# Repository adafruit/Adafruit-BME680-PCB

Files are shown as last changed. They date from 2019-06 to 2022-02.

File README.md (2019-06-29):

## Adafruit BME680 PCB

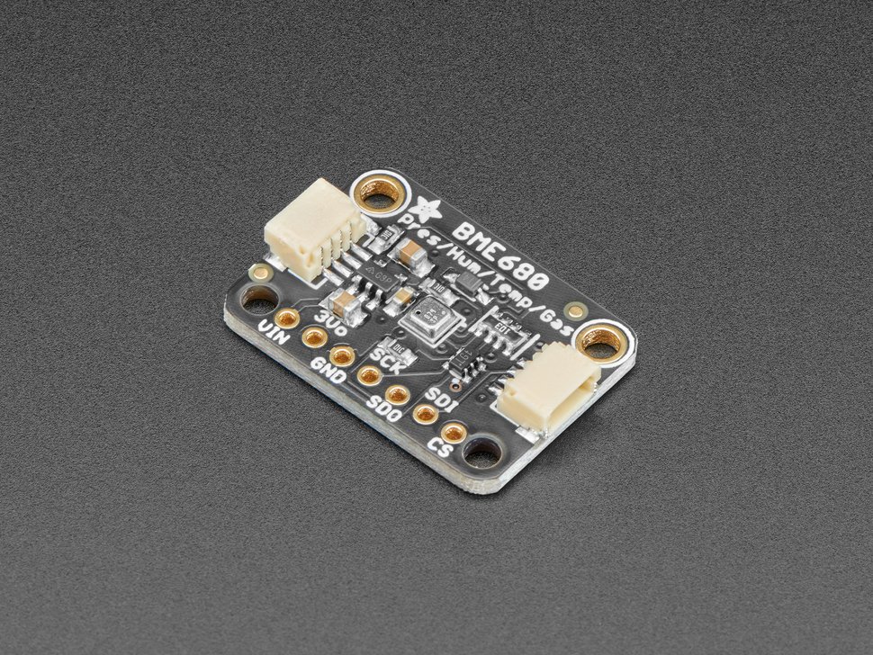
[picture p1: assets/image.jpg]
<a href="http://www.adafruit.com/products/3660"><br/>
Click here to purchase one from the Adafruit shop</a>

PCB files for the Adafruit BME680 Breakout. Format is EagleCAD schematic and board layout

For more details, check out the product page at
* https://www.adafruit.com/product/3660

### Description

The long awaited BME680 from Bosch gives you all the environmental sensing you want in one small package. This little sensor contains temperature, humidity, barometric pressure, and VOC gas sensing capabilities. All over SPI or I2C at a great price!

Like the BME280 & BMP280, this precision sensor from Bosch can measure humidity with ±3% accuracy, barometric pressure with ±1 hPa absolute accuracy, and temperature with ±1.0°C accuracy. Because pressure changes with altitude, and the pressure measurements are so good, you can also use it as an altimeter with  ±1 meter or better accuracy!

The BME680 takes those sensors to the next step in that it contains a small MOX sensor. The heated metal oxide changes resistance based on the volatile organic compounds (VOC) in the air, so it can be used to detect gasses & alcohols such as Ethanol, Alcohol and Carbon Monoxide, and perform air quality measurements. Note it will give you one resistance value, with overall VOC content, but it cannot differentiate gasses or alcohols.

Please note this sensor, like all VOC/gas sensors, has variability and to get precise measurements you will want to calibrate it against known sources! That said, for general environmental sensors, it will give you a good idea of trends and comparisons. We recommend that you run this sensor for 48 hours when you first receive it to "burn it in", and then 30 minutes in the desired mode every time the sensor is in use. This is because the sensitivity levels of the sensor will change during early use, and the resistance will slowly rise over time as the MOX warms up to its baseline reading.

For your convenience we've pick-and-placed the sensor on a PCB with a 3.3V regulator and some level shifting, so it can be easily used with your favorite 3.3V or 5V microcontroller.

### License

Adafruit invests time and resources providing this open source design, please support Adafruit and open-source hardware by purchasing products from [Adafruit](https://www.adafruit.com)!

Designed by Limor Fried/Ladyada for Adafruit Industries.

Creative Commons Attribution/Share-Alike, all text above must be included in any redistribution. See license.txt for additional details.

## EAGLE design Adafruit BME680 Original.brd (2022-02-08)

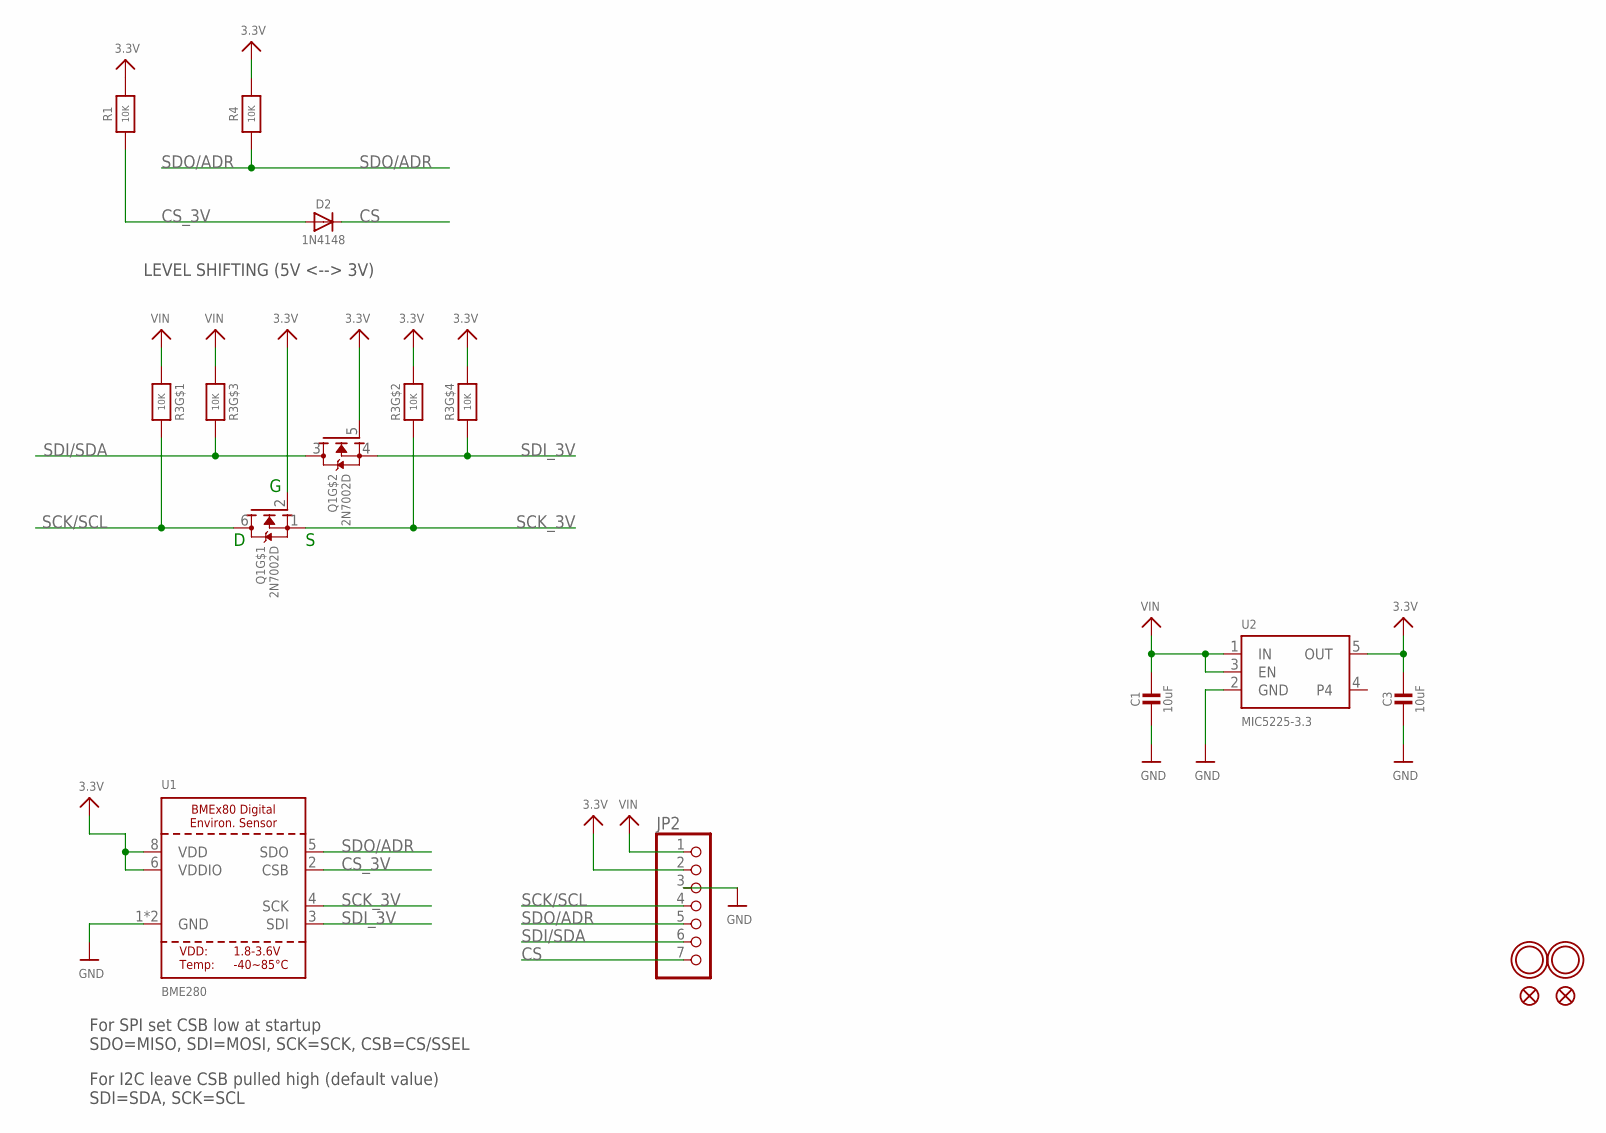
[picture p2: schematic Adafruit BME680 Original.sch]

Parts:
C1, C3: 10uF; 0805-NO
D2: 1N4148; SOD-323
JP2: HEADER-1X770MIL; 1X07_ROUND_70
Q1: 2N7002D; SOT363
R1, R4: 10K; 0603-NO
R3: 10K; RESPACK_4X0603
U1: BME280; BME680
U2: MIC5225-3.3; SOT23-5
U$5, U$15: FIDUCIAL_1MM
U$7, U$8: MOUNTINGHOLE2.0; MOUNTINGHOLE_2.0_PLATED

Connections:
3.3V: C3.1, JP2.2, Q1.2 (G), Q1.5 (G), R1.2, R3.2 (1), R3.4 (1), R4.2, U1.6 (VDDIO), U1.8 (VDD), U2.5 (OUT)
CS: D2.C, JP2.7
CS_3V: D2.A, R1.1, U1.2 (CSB)
GND: C1.2, C3.2, JP2.3, U1.1 (GND), U1.7 (GND), U2.2 (GND)
SCK/SCL: JP2.4, Q1.6 (D), R3.8 (2)
SCK_3V: Q1.1 (S), R3.7 (2), U1.4 (SCK)
SDI/SDA: JP2.6, Q1.3 (D), R3.6 (2)
SDI_3V: Q1.4 (S), R3.5 (2), U1.3 (SDI)
SDO/ADR: JP2.5, R4.1, U1.5 (SDO)
VIN: C1.1, JP2.1, R3.1, R3.3 (1), U2.1 (IN), U2.3 (EN)

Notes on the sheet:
For SPI set CSB low at startup SDO=MISO, SDI=MOSI, SCK=SCK, CSB=CS/SSEL
For I2C leave CSB pulled high (default value) SDI=SDA, SCK=SCL
LEVEL SHIFTING (5V <--> 3V)

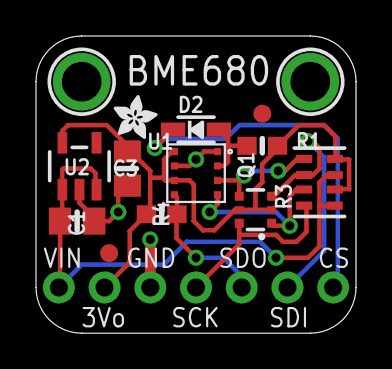
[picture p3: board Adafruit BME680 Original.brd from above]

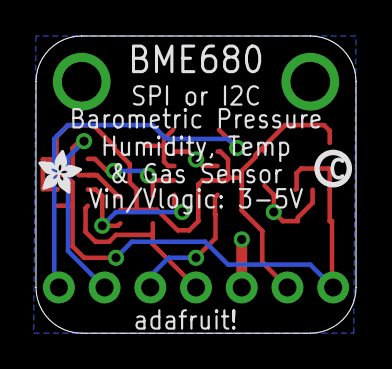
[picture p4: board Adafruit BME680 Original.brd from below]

Board: 2 copper layers, 17.8 x 16.5 mm, 17 parts (2 on the bottom side), 10 nets.

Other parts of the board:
U$2, U$6: ADAFRUIT_2.5MM
U$20: PCBFEAT-REV-040

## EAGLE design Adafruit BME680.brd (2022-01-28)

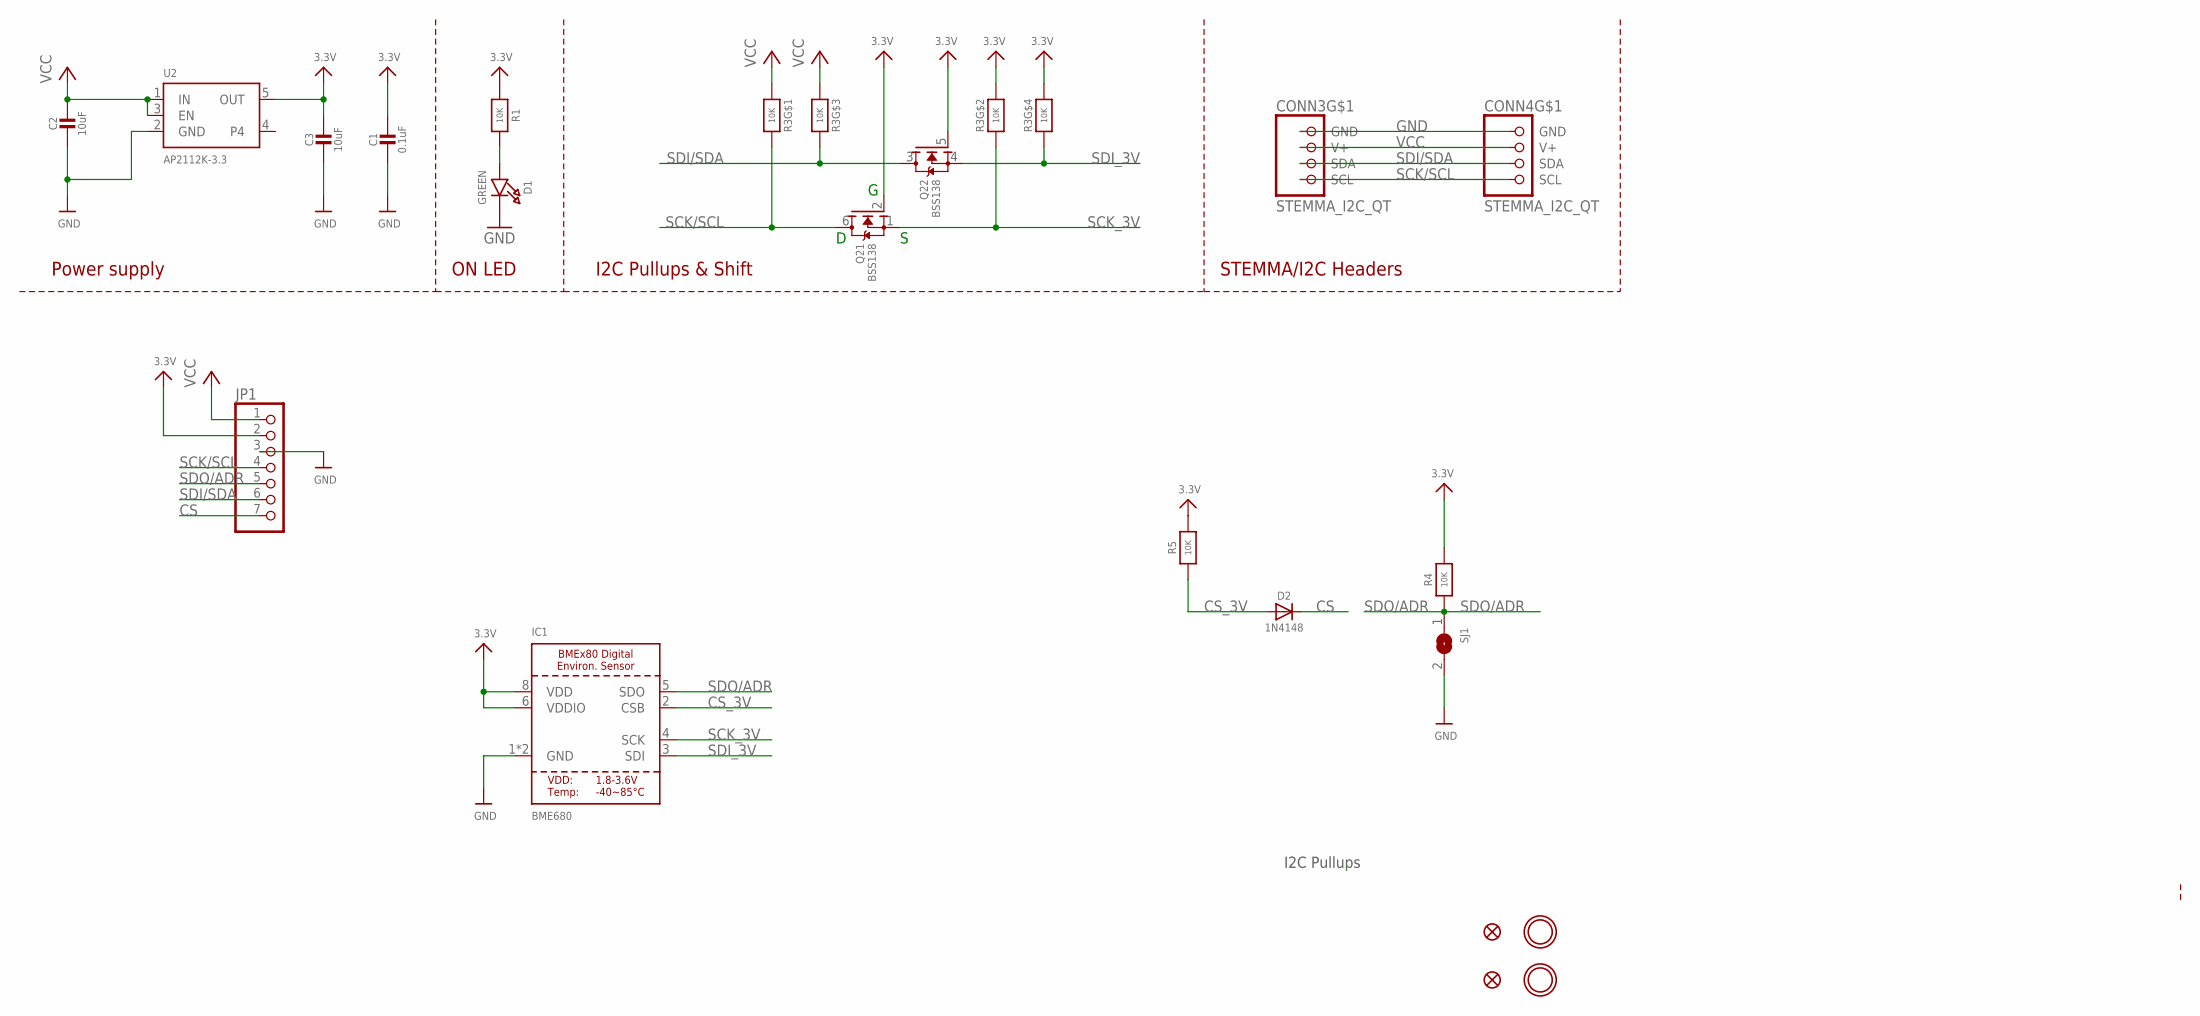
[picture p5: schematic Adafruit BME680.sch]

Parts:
C1: 0.1uF; 0603-NO
C2, C3: 10uF; 0805-NO
CONN3, CONN4: STEMMA_I2C_QT; JST_SH4
D1: GREEN; CHIPLED_0603_NOOUTLINE
D2: 1N4148; SOD-323
FID3, FID4: FIDUCIAL_1MM
IC1: BME680
JP1: HEADER-1X770MIL; 1X07_ROUND_70
Q2: BSS138; SOT363
R1, R4, R5: 10K; 0603-NO
R3: 10K; RESPACK_4X0603
SJ1: SOLDERJUMPER; SOLDERJUMPER_ARROW_NOPASTE
U2: AP2112K-3.3; SOT23-5
U$1, U$17: MOUNTINGHOLE2.5; MOUNTINGHOLE_2.5_PLATED

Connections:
3.3V: C1.1, C3.1, IC1.6 (VDDIO), IC1.8 (VDD), JP1.2, Q2.2 (G), Q2.5 (G), R1.1, R3.2 (1), R3.4 (1), R4.2, R5.2, U2.5 (OUT)
CS: D2.C, JP1.7
CS_3V: D2.A, IC1.2 (CSB), R5.1
GND: C1.2, C2.2, C3.2, CONN3.1 (GND), CONN4.1 (GND), D1.C, IC1.1 (GND), IC1.7 (GND), JP1.3, SJ1.2, U2.2 (GND)
unnamed: D1.A, R1.2
SCK/SCL: CONN3.4 (SCL), CONN4.4 (SCL), JP1.4, Q2.6 (D), R3.8 (2)
SCK_3V: IC1.4 (SCK), Q2.1 (S), R3.7 (2)
SDI/SDA: CONN3.3 (SDA), CONN4.3 (SDA), JP1.6, Q2.3 (D), R3.6 (2)
SDI_3V: IC1.3 (SDI), Q2.4 (S), R3.5 (2)
SDO/ADR: IC1.5 (SDO), JP1.5, R4.1, SJ1.1
VCC: C2.1, CONN3.2 (V+), CONN4.2 (V+), JP1.1, R3.1, R3.3 (1), U2.1 (IN), U2.3 (EN)

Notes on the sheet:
I2C Pullups & Shift
STEMMA/I2C Headers
ON LED
Power supply
I2C Pullups

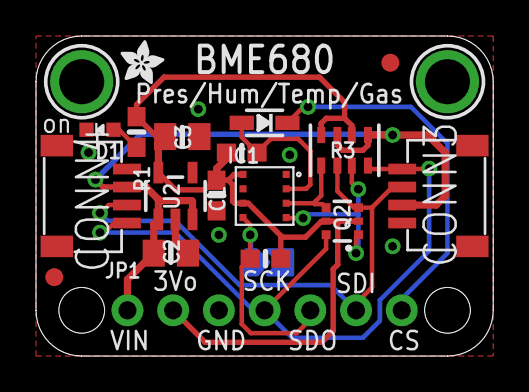
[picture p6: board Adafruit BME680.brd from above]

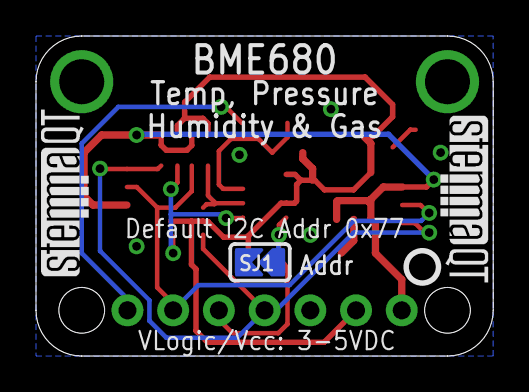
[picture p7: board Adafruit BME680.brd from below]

Board: 2 copper layers, 25.4 x 17.8 mm, 24 parts (4 on the bottom side), 11 nets.

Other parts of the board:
U$4: ADAFRUIT_2.5MM
U$25: PCBFEAT-REV-040
U$30, U$31: STEMMAQT

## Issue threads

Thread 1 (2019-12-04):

Incorrect footprint for BME680

LukaszWoj, 2019-12-04:
The PCB file has the incorrect footprint - the BME280 is in the place of the BME680.

This results in the pitch of the PCB pads not being 0.8mm and instead are 0.65mm and will have soldering problems.

The schematic object also causes confusion, it is marked **BMEx80** which can lead to thinking that the BME280 and BME680 are interchangeable which is not the case..

Thank you!

caternuson, 2019-12-04:
Good catch. This repo just needs updated with latest PCB files.

ATM-HSW, 2022-01-28:
The CAD files still contains the wrong packages - it's a BME280 not a BME680
An update would be great.

ATM-HSW, 2022-02-04:
I think, this issue can be closed because it is solved.

Closed 2022-02-04.

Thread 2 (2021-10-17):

Update PCB with Stemma QT version

timonvo, 2021-10-17:
In August 2020 the PCB was redesigned with Stemma QT support (https://www.adafruit.com/product/3660). Would it be possible to get the updated schematics uploaded to this repo?

ATM-HSW, 2022-01-28:
Any news about uploading the Stemma QT version of the sensor board?

kattni, 2022-01-28:
I missed this one! I'll get it uploaded by next week!

ATM-HSW, 2022-02-04:
I think, this issue can be closed because it is solved.

Closed 2022-02-04.

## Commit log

2022-01-28 Updated PCB files
    [Adafruit BME680.brd, Adafruit BME680.sch]
2022-02-08 Readd original board files.
    [Adafruit BME680 Original.brd, Adafruit BME680 Original.sch]

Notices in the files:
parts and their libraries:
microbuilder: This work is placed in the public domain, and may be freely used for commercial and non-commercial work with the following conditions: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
